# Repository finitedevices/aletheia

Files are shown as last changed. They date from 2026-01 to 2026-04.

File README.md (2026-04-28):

# Aletheia
Designs and resources for the Finite Aletheia: a versatile, 8-bit hand-bootstrapped computer.

## Building and running the simulator
Before building the simulator for the first time, ensure that development dependencies are installed by running:

```bash
cd simulator
./build.sh --install-dev
```

Once the dependencies are installed, the Aletheia simulator can be built and run by running the following in the `simulator` directory:

```bash
./build.sh && python3 -m http.server
```

The simulator will then be available at [localhost:8000](http://localhost:8000).

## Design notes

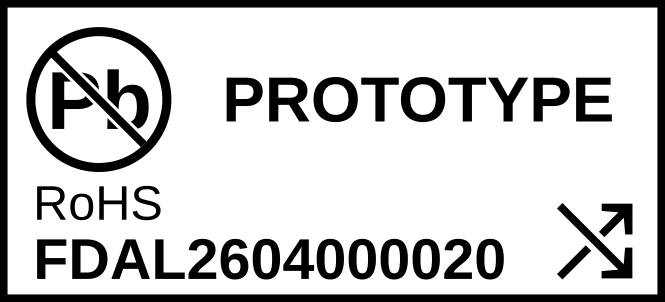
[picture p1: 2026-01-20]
hardware/Back-Cutout.png

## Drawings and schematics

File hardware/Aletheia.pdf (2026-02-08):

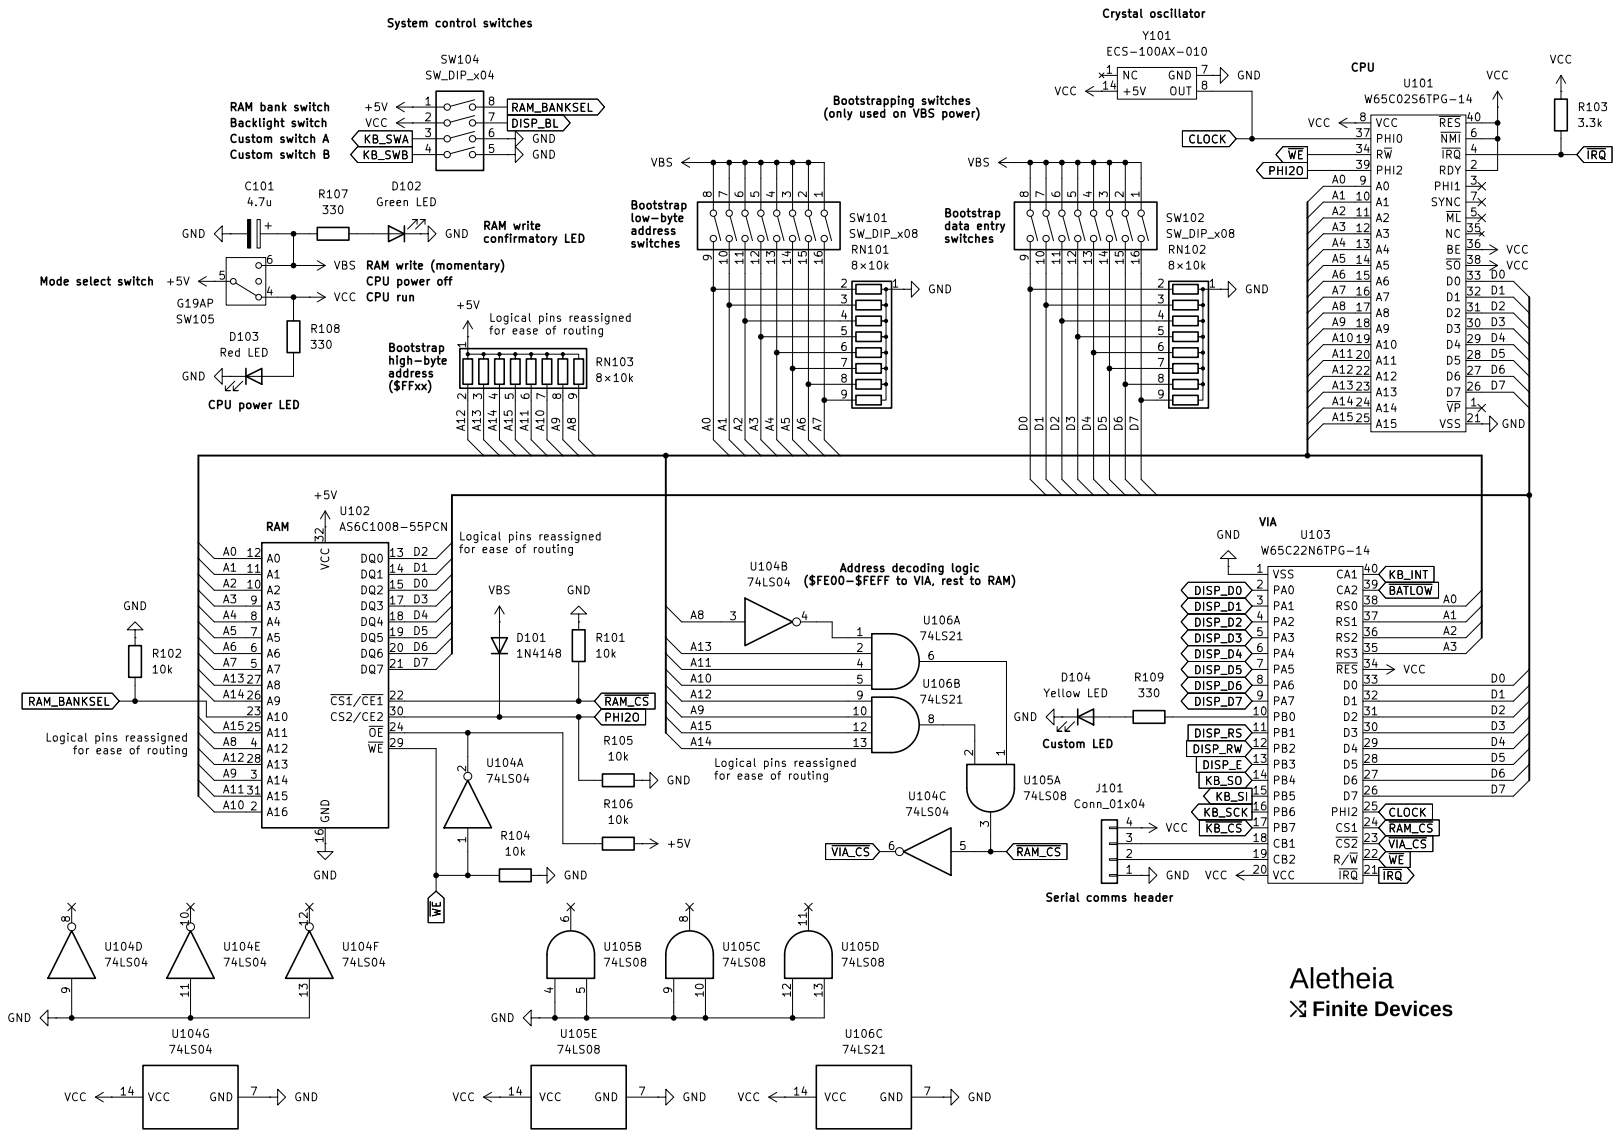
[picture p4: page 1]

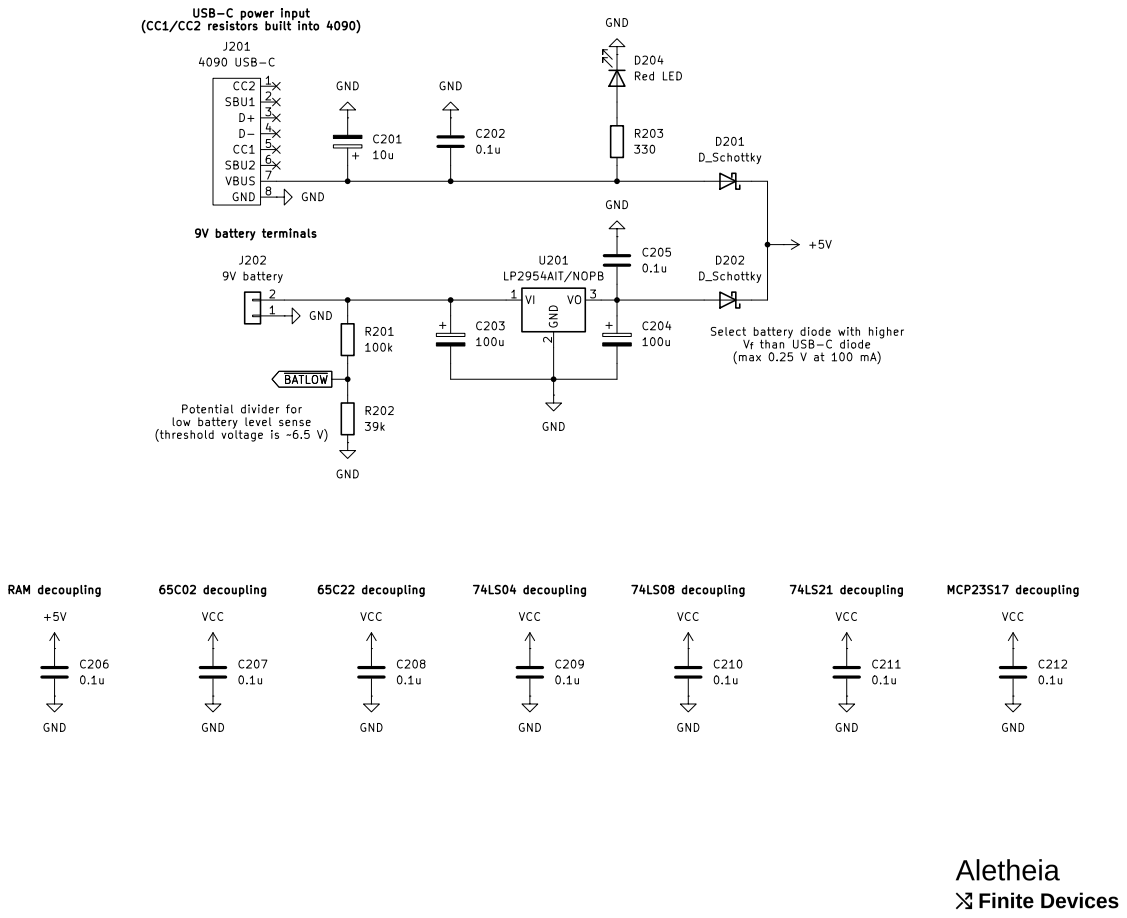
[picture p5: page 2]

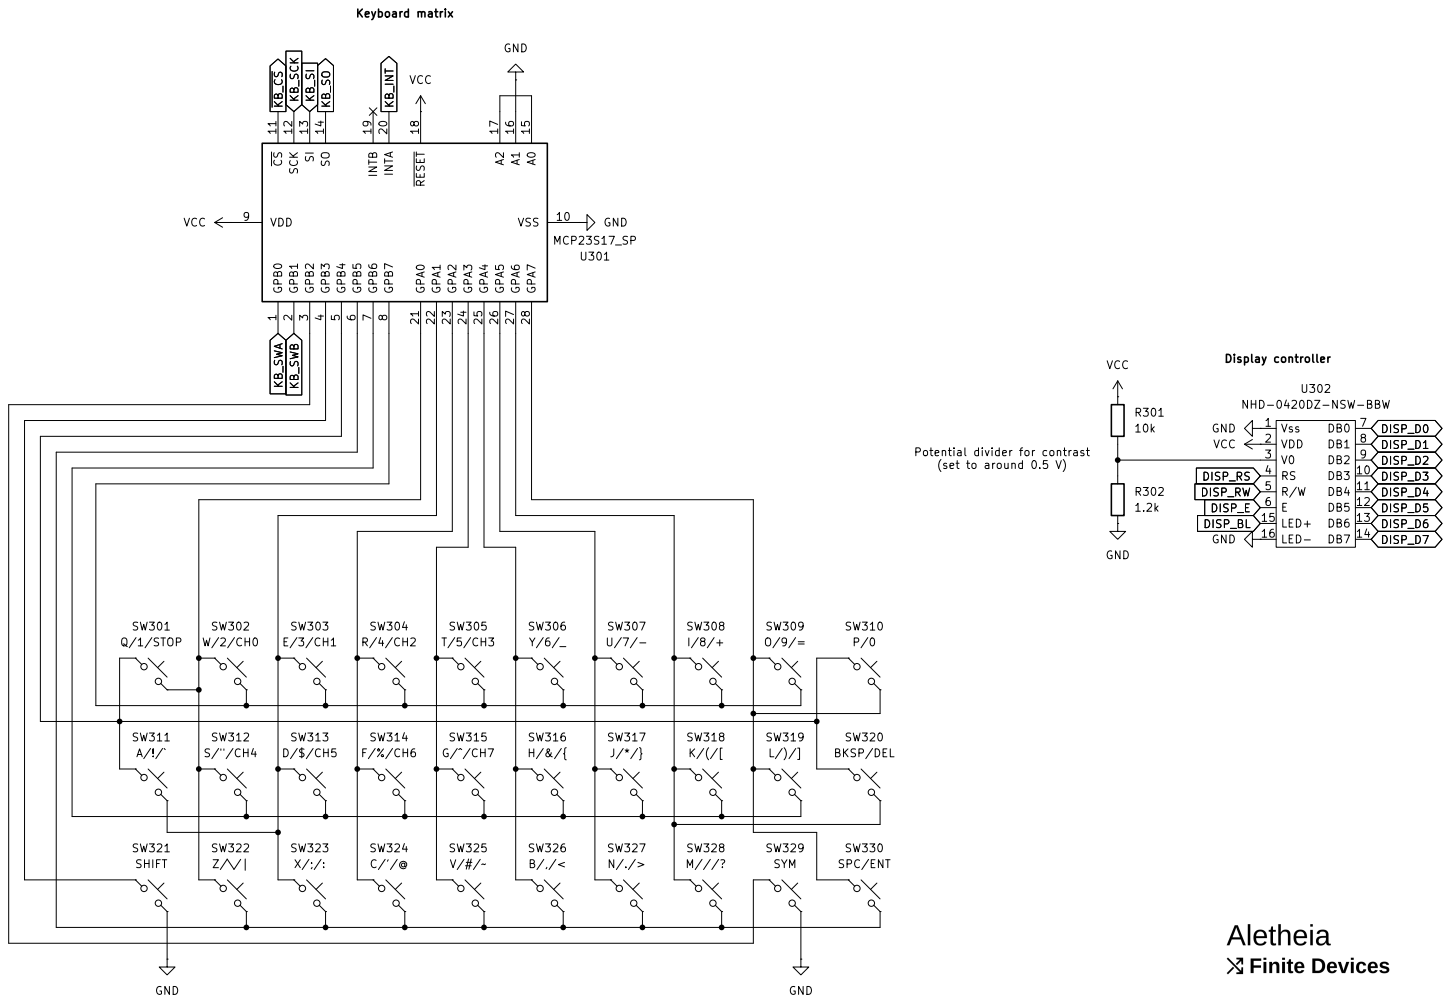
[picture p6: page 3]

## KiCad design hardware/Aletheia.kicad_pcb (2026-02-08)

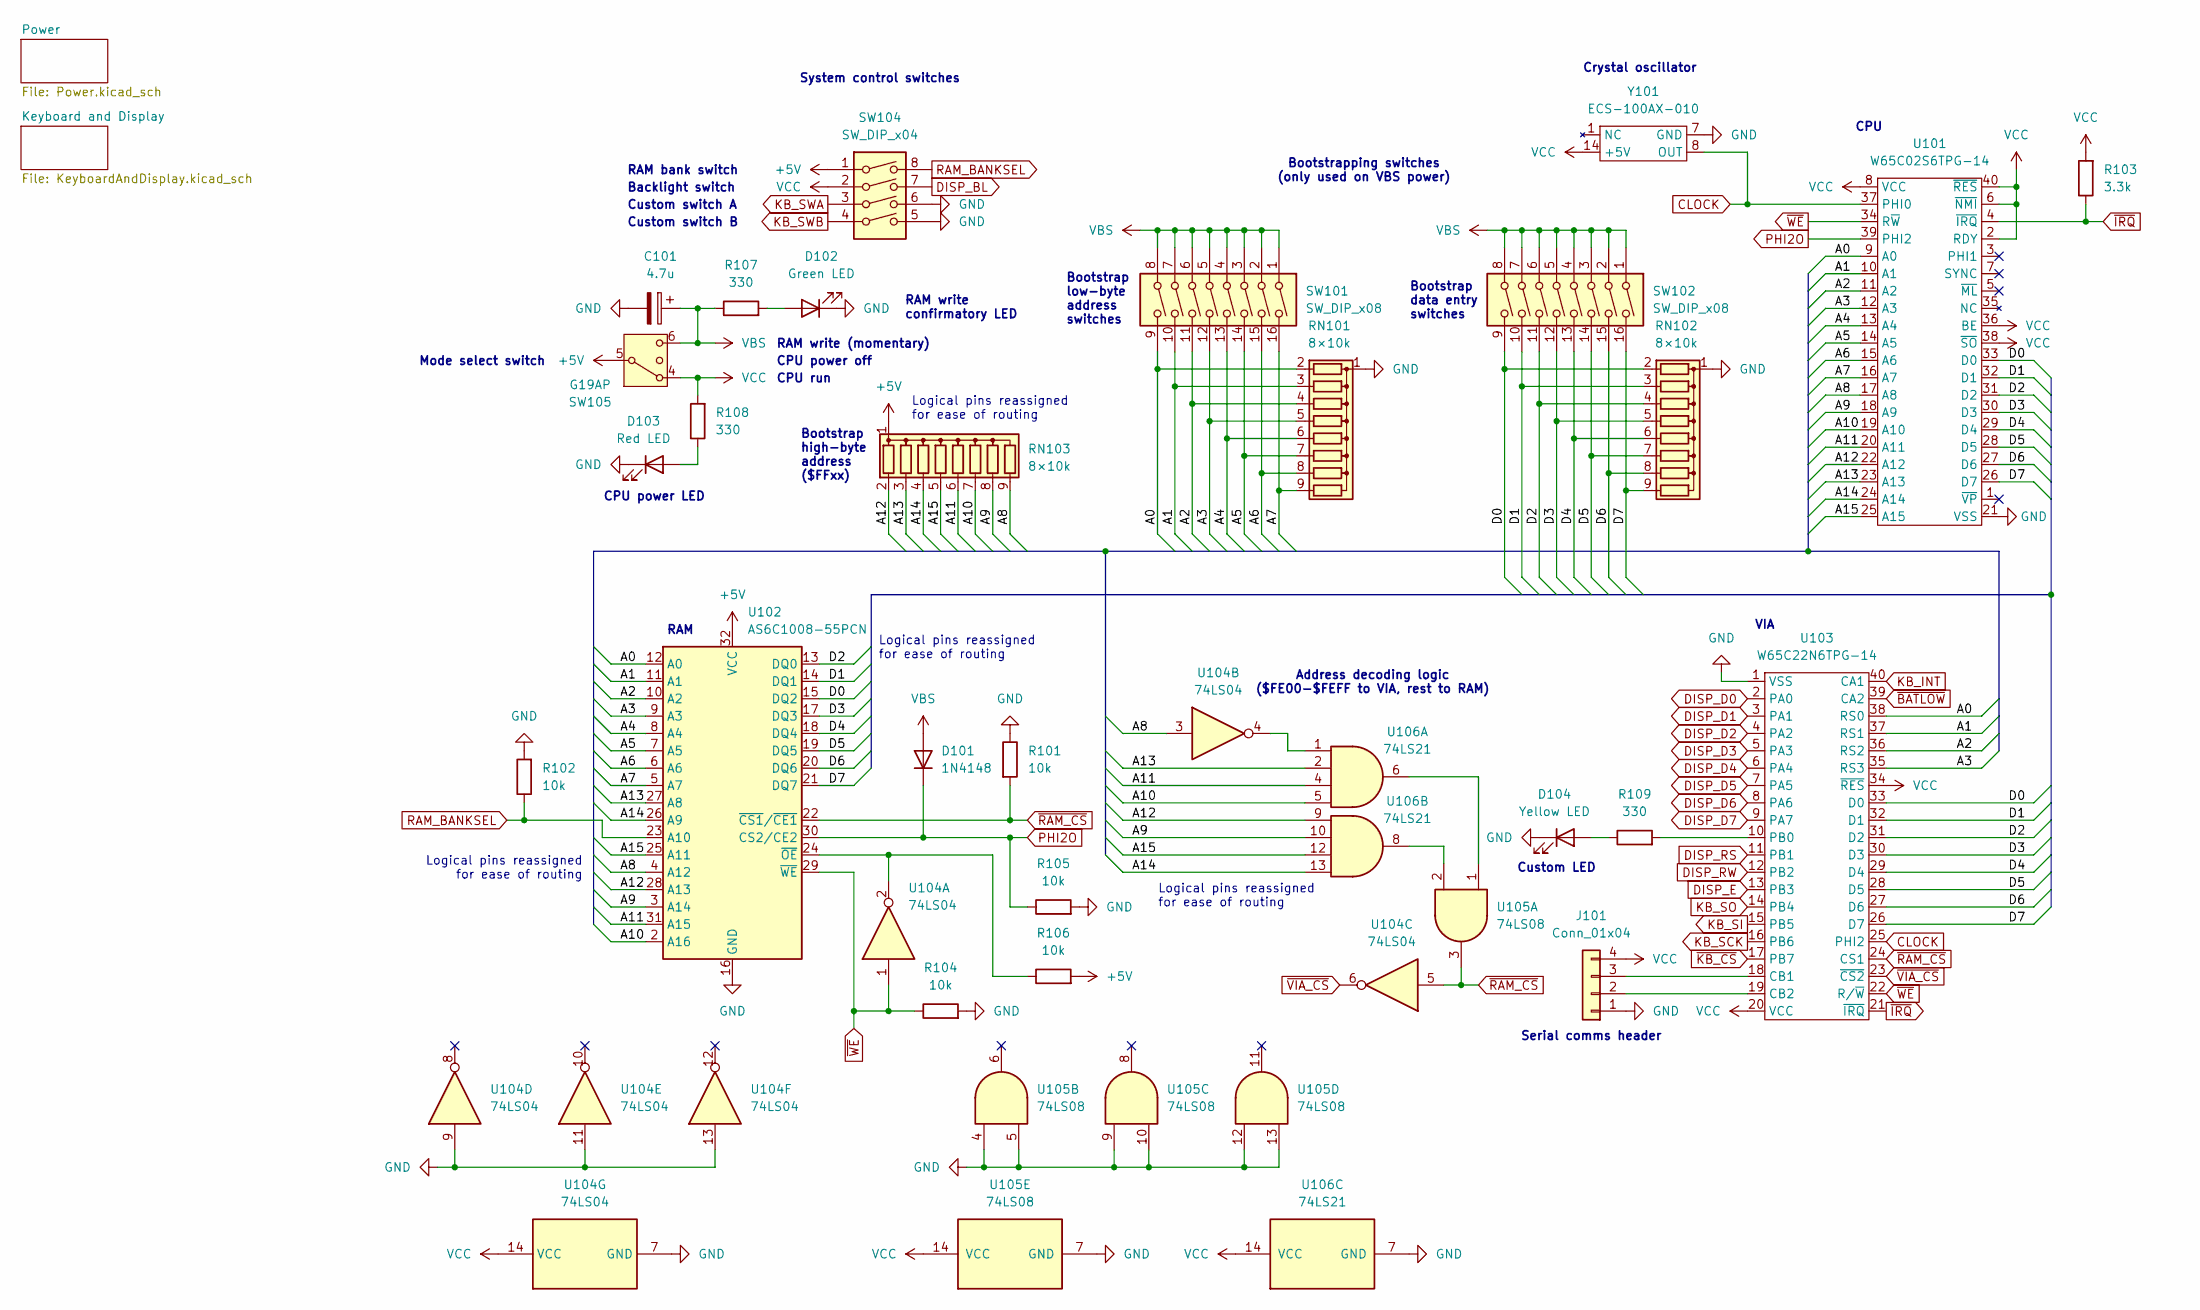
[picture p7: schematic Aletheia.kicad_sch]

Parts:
C101: 4.7u; CP_Radial_D5.0mm_P2.00mm
D101: 1N4148; D_DO-35_SOD27_P7.62mm_Horizontal
D102: Green LED; LED_D5.0mm
D103: Red LED; LED_D5.0mm
D104: Yellow LED; LED_D5.0mm
J101: Conn_01x04; PinHeader_1x04_P2.54mm_Vertical
R101, R102, R104, R105, R106: 10k; R_Axial_DIN0207_L6.3mm_D2.5mm_P7.62mm_Horizontal
R103: 3.3k; R_Axial_DIN0207_L6.3mm_D2.5mm_P7.62mm_Horizontal
R107, R108, R109: 330; R_Axial_DIN0207_L6.3mm_D2.5mm_P7.62mm_Horizontal
RN101, RN102, RN103: 8×10k; R_Array_SIP9
SW101, SW102: SW_DIP_x08; SW_DIP_SPSTx08_Slide_9.78x22.5mm_W7.62mm_P2.54mm
SW104: SW_DIP_x04; SW_DIP_SPSTx04_Slide_9.78x12.34mm_W7.62mm_P2.54mm
SW105: G19AP
U101: W65C02S6TPG-14; DIP-40_W15.24mm_LongPads
U102: AS6C1008-55PCN; DIP-32_W15.24mm
U103: W65C22N6TPG-14; DIP-40_W15.24mm
U104: 74LS04; DIP-14_W7.62mm
U105: 74LS08; DIP-14_W7.62mm
U106: 74LS21; DIP-14_W7.62mm
Y101: ECS-100AX-010

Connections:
+5V: R106.2, RN103.1 (common), SW104.1, SW105.5, U102.32 (VCC); also elsewhere on the board
/A0: RN101.2 (R1), SW101.9, U101.9 (A0), U102.12 (A0), U103.38 (RS0)
/A1: RN101.3 (R2), SW101.10, U101.10 (A1), U102.11 (A1), U103.37 (RS1)
/A2: RN101.4 (R3), SW101.11, U101.11 (A2), U102.10 (A2), U103.36 (RS2)
/A3: RN101.5 (R4), SW101.12, U101.12 (A3), U102.9 (A3), U103.35 (RS3)
/A4: RN101.6 (R5), SW101.13, U101.13 (A4), U102.8 (A4)
/A5: RN101.7 (R6), SW101.14, U101.14 (A5), U102.7 (A5)
/A6: RN101.8 (R7), SW101.15, U101.15 (A6), U102.6 (A6)
/A7: RN101.9 (R8), SW101.16, U101.16 (A7), U102.5 (A7)
/A8: RN103.9 (R8), U101.17 (A8), U102.4 (A12), U104.3
/A9: RN103.8 (R7), U101.18 (A9), U102.3 (A14), U106.10
/A10: RN103.7 (R6), U101.19 (A10), U102.2 (A16), U106.5
/A11: RN103.6 (R5), U101.20 (A11), U102.31 (A15), U106.4
/A12: RN103.2 (R1), U101.22 (A12), U102.28 (A13), U106.9
/A13: RN103.3 (R2), U101.23 (A13), U102.27 (A8), U106.2
/A14: RN103.4 (R3), U101.24 (A14), U102.26 (A9), U106.13
/A15: RN103.5 (R4), U101.25 (A15), U102.25 (A11), U106.12
/D0: RN102.2 (R1), SW102.9, U101.33 (D0), U102.15 (DQ2), U103.33 (D0)
/D1: RN102.3 (R2), SW102.10, U101.32 (D1), U102.14 (DQ1), U103.32 (D1)
/D2: RN102.4 (R3), SW102.11, U101.31 (D2), U102.13 (DQ0), U103.31 (D2)
/D3: RN102.5 (R4), SW102.12, U101.30 (D3), U102.17 (DQ3), U103.30 (D3)
/D4: RN102.6 (R5), SW102.13, U101.29 (D4), U102.18 (DQ4), U103.29 (D4)
/D5: RN102.7 (R6), SW102.14, U101.28 (D5), U102.19 (DQ5), U103.28 (D5)
/D6: RN102.8 (R7), SW102.15, U101.27 (D6), U102.20 (DQ6), U103.27 (D6)
/D7: RN102.9 (R8), SW102.16, U101.26 (D7), U102.21 (DQ7), U103.26 (D7)
CLOCK: U101.37 (PHI0), U103.25 (PHI2), Y101.8 (OUT)
DISP_BL: SW104.7; also elsewhere on the board
DISP_D0: U103.2 (PA0); also elsewhere on the board
DISP_D1: U103.3 (PA1); also elsewhere on the board
DISP_D2: U103.4 (PA2); also elsewhere on the board
DISP_D3: U103.5 (PA3); also elsewhere on the board
DISP_D4: U103.6 (PA4); also elsewhere on the board
DISP_D5: U103.7 (PA5); also elsewhere on the board
DISP_D6: U103.8 (PA6); also elsewhere on the board
DISP_D7: U103.9 (PA7); also elsewhere on the board
DISP_E: U103.13 (PB3); also elsewhere on the board
DISP_RS: U103.11 (PB1); also elsewhere on the board
DISP_RW: U103.12 (PB2); also elsewhere on the board
GND: C101.2, D102.1 (K), D103.1 (K), D104.1 (K), J101.1, R101.1, R102.2, R104.2, R105.2, RN101.1 (common), RN102.1 (common), SW104.5, SW104.6, U101.21 (VSS), U102.16 (GND), U103.1 (VSS), U104.7 (GND), U104.9, U104.11, U104.13, U105.4, U105.5, U105.7 (GND), U105.9, U105.10, U105.12, U105.13, U106.7 (GND), Y101.7 (GND); also elsewhere on the board
KB_INT: U103.40 (CA1); also elsewhere on the board
KB_SCK: U103.16 (PB6); also elsewhere on the board
KB_SI: U103.15 (PB5); also elsewhere on the board
KB_SO: U103.14 (PB4); also elsewhere on the board
KB_SWA: SW104.3; also elsewhere on the board
KB_SWB: SW104.4; also elsewhere on the board
unnamed: D102.2 (A), R107.2
unnamed: D103.2 (A), R108.1
unnamed: D104.2 (A), R109.1
unnamed: J101.2, U103.19 (CB2)
unnamed: J101.3, U103.18 (CB1)
unnamed: R106.1, U102.24 (~OE), U104.2
unnamed: R109.2, U103.10 (PB0)
unnamed: U104.4, U106.1
unnamed: U105.1, U106.6
unnamed: U105.2, U106.8
PHI2O: D101.1 (K), R105.1, U101.39 (PHI2), U102.30 (CS2/CE2)
RAM_BANKSEL: R102.1, SW104.8, U102.23 (A10)
VBS: C101.1, D101.2 (A), R107.1, SW101.1, SW101.2, SW101.3, SW101.4, SW101.5, SW101.6, SW101.7, SW101.8, SW102.1, SW102.2, SW102.3, SW102.4, SW102.5, SW102.6, SW102.7, SW102.8, SW105.6
VCC: J101.4, R103.2, R108.2, SW104.2, SW105.4, U101.2 (RDY), U101.6 (~NMI), U101.8 (VCC), U101.36 (BE), U101.38 (~SO), U101.40 (~RES), U103.20 (VCC), U103.34 (~RES), U104.14 (VCC), U105.14 (VCC), U106.14 (VCC), Y101.14 (+5V); also elsewhere on the board
~BATLOW: U103.39 (CA2); also elsewhere on the board
~IRQ: R103.1, U101.4 (~IRQ), U103.21 (~IRQ)
~KB_CS: U103.17 (PB7); also elsewhere on the board
~RAM_CS: R101.2, U102.22 (~CS1/~CE1), U103.24 (CS1), U104.5, U105.3
~VIA_CS: U103.23 (~CS2), U104.6
~WE: R104.1, U101.34 (R~W), U102.29 (~WE), U103.22 (R/~W), U104.1

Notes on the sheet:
Custom switch A
RAM
CPU
CPU run
Crystal oscillator
RAM write (momentary)
Bootstrap low-byte address switches
CPU power off
Bootstrap high-byte address ($FFxx)
Bootstrap data entry switches
Serial comms header
CPU power LED
Address decoding logic ($FE00-$FEFF to VIA, rest to RAM)
RAM write confirmatory LED
Bootstrapping switches (only used on VBS power)
Logical pins reassigned for ease of routing
VIA
Mode select switch
Backlight switch
RAM bank switch
Custom LED
System control switches
Custom switch B

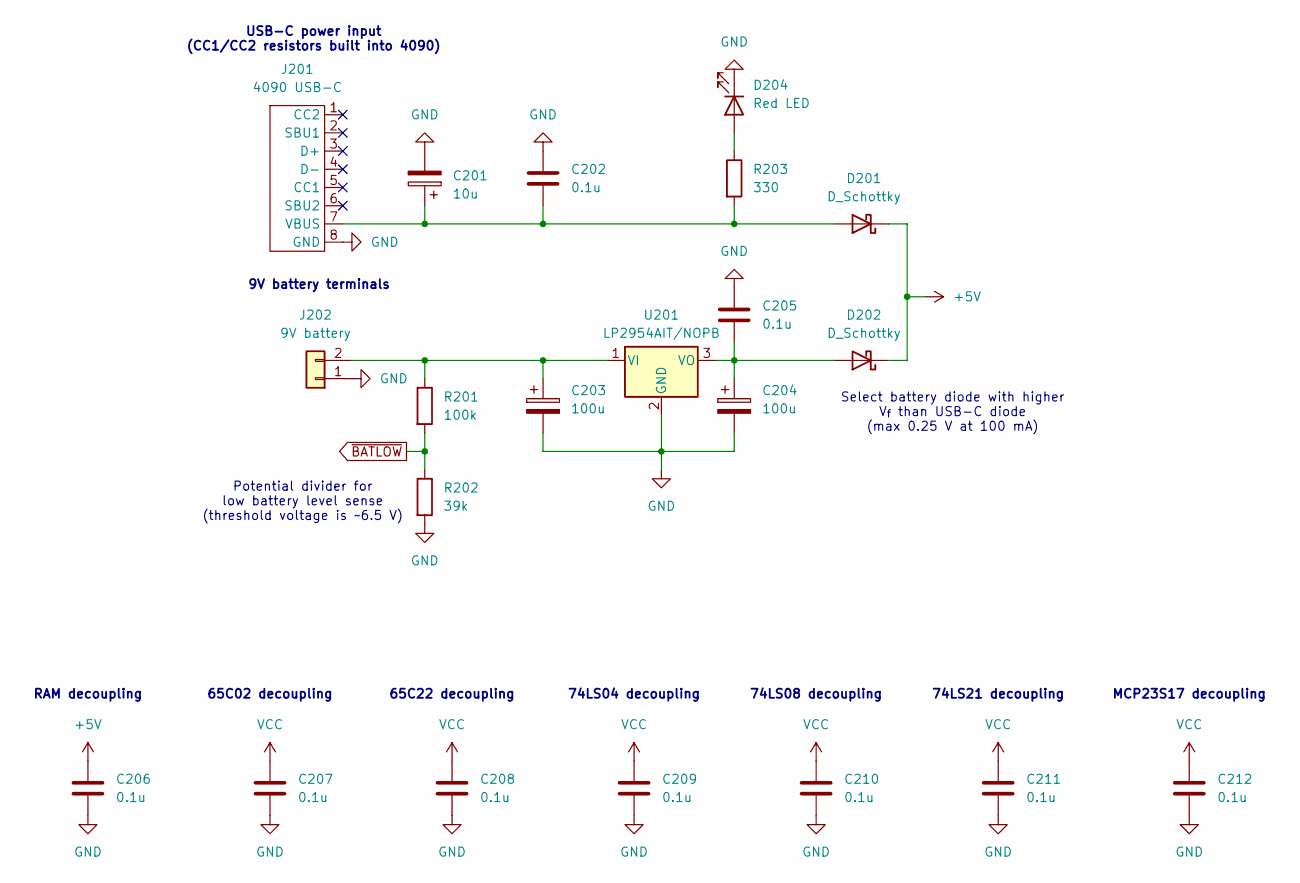
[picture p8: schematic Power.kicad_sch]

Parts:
C201: 10u; CP_Radial_D5.0mm_P2.00mm
C202: 0.1u; CP_Radial_D4.0mm_P1.50mm
C203, C204: 100u; CP_Radial_D6.3mm_P2.50mm
C205, C206, C207, C208, C209, C210, C211, C212: 0.1u; C_Radial_D4.0mm_H5.0mm_P1.50mm
D201, D202: D_Schottky; D_DO-41_SOD81_P7.62mm_Horizontal
D204: Red LED; LED_D5.0mm
J201: 4090 USB-C; PinHeader_1x08_P2.54mm_Vertical
J202: 9V battery; PinHeader_2x01_P2.54mm_Vertical
R201: 100k; R_Axial_DIN0207_L6.3mm_D2.5mm_P7.62mm_Horizontal
R202: 39k; R_Axial_DIN0207_L6.3mm_D2.5mm_P7.62mm_Horizontal
R203: 330; R_Axial_DIN0207_L6.3mm_D2.5mm_P7.62mm_Horizontal
U201: LP2954AIT/NOPB; TO-220-3_Vertical

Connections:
+5V: C206.1, D201.1 (K), D202.1 (K); also elsewhere on the board
GND: C201.2, C202.1, C203.2, C204.2, C205.1, C206.2, C207.2, C208.2, C209.2, C210.2, C211.2, C212.2, D204.1 (K), J201.8 (GND), J202.1, R202.2, U201.2 (GND); also elsewhere on the board
unnamed: C201.1, C202.2, D201.2 (A), J201.7 (VBUS), R203.2
unnamed: C204.1, C205.2, D202.2 (A), U201.3 (VO)
unnamed: D204.2 (A), R203.1
unnamed: C203.1, J202.2, R201.1, U201.1 (VI)
VCC: C207.1, C208.1, C209.1, C210.1, C211.1, C212.1; also elsewhere on the board
~BATLOW: R201.2, R202.1; also elsewhere on the board

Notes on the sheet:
RAM decoupling
74LS08 decoupling
MCP23S17 decoupling
Select battery diode with higher V_{f} than USB-C diode (max 0.25 V at 100 mA)
9V battery terminals
74LS04 decoupling
74LS21 decoupling
USB-C power input (CC1/CC2 resistors built into 4090)
65C02 decoupling
65C22 decoupling
Potential divider for low battery level sense (threshold voltage is ~6.5 V)

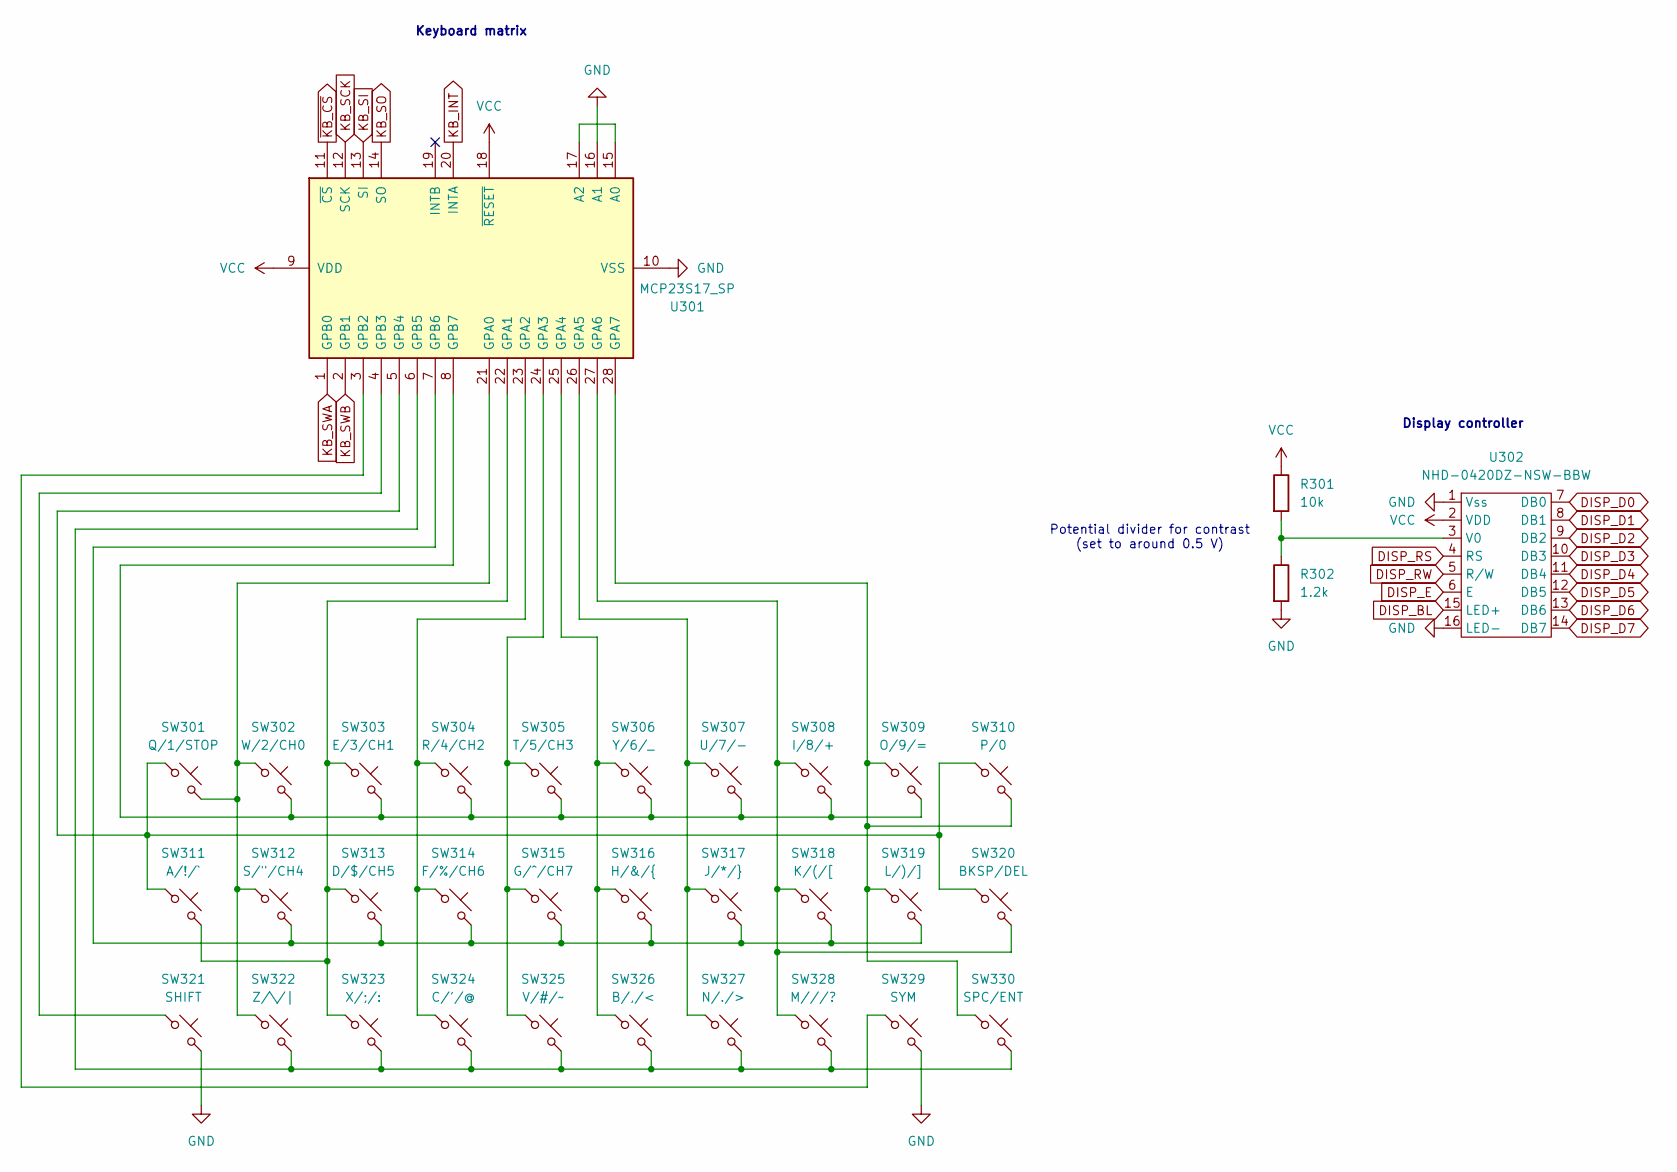
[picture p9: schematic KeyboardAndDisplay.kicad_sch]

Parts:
R301: 10k; R_Axial_DIN0207_L6.3mm_D2.5mm_P7.62mm_Horizontal
R302: 1.2k; R_Axial_DIN0207_L6.3mm_D2.5mm_P7.62mm_Horizontal
SW301: Q/1/STOP; SW_PUSH_6mm
SW302: W/2/CH0; SW_PUSH_6mm
SW303: E/3/CH1; SW_PUSH_6mm
SW304: R/4/CH2; SW_PUSH_6mm
SW305: T/5/CH3; SW_PUSH_6mm
SW306: Y/6/_; SW_PUSH_6mm
SW307: U/7/-; SW_PUSH_6mm
SW308: I/8/+; SW_PUSH_6mm
SW309: O/9/=; SW_PUSH_6mm
SW310: P/0; SW_PUSH_6mm
SW311: A/!/`; SW_PUSH_6mm
SW312: S/"/CH4; SW_PUSH_6mm
SW313: D/$/CH5; SW_PUSH_6mm
SW314: F/%/CH6; SW_PUSH_6mm
SW315: G/^/CH7; SW_PUSH_6mm
SW316: H/&/{; SW_PUSH_6mm
SW317: J/*/}; SW_PUSH_6mm
SW318: K/(/[; SW_PUSH_6mm
SW319: L/)/]; SW_PUSH_6mm
SW320: BKSP/DEL; SW_PUSH_6mm
SW321: SHIFT; SW_PUSH_6mm
SW322: Z/\/|; SW_PUSH_6mm
SW323: X/;/:; SW_PUSH_6mm
SW324: C/'/@; SW_PUSH_6mm
SW325: V/#/~; SW_PUSH_6mm
SW326: B/,/<; SW_PUSH_6mm
SW327: N/./>; SW_PUSH_6mm
SW328: M///?; SW_PUSH_6mm
SW329: SYM; SW_PUSH_6mm
SW330: SPC/ENT; SW_PUSH_6mm
U301: MCP23S17_SP; DIP-28_W7.62mm
U302: NHD-0420DZ-NSW-BBW; NHD-0420DZ-FL-YBW

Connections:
DISP_BL: U302.15 (LED+); also elsewhere on the board
DISP_D0: U302.7 (DB0); also elsewhere on the board
DISP_D1: U302.8 (DB1); also elsewhere on the board
DISP_D2: U302.9 (DB2); also elsewhere on the board
DISP_D3: U302.10 (DB3); also elsewhere on the board
DISP_D4: U302.11 (DB4); also elsewhere on the board
DISP_D5: U302.12 (DB5); also elsewhere on the board
DISP_D6: U302.13 (DB6); also elsewhere on the board
DISP_D7: U302.14 (DB7); also elsewhere on the board
DISP_E: U302.6 (E); also elsewhere on the board
DISP_RS: U302.4 (RS); also elsewhere on the board
DISP_RW: U302.5 (R/W); also elsewhere on the board
GND: R302.2, SW321.2, SW329.2, U301.10 (VSS), U301.16 (A1), U302.1 (Vss), U302.16 (LED-); also elsewhere on the board
KB_INT: U301.20 (INTA); also elsewhere on the board
KB_SCK: U301.12 (SCK); also elsewhere on the board
KB_SI: U301.13 (SI); also elsewhere on the board
KB_SO: U301.14 (SO); also elsewhere on the board
KB_SWA: U301.1 (GPB0); also elsewhere on the board
KB_SWB: U301.2 (GPB1); also elsewhere on the board
unnamed: U301.15 (A0), U301.17 (A2)
unnamed: SW301.2, SW302.1, SW312.1, SW322.1, U301.21 (GPA0)
unnamed: SW303.1, SW311.2, SW313.1, SW323.1, U301.22 (GPA1)
unnamed: SW304.1, SW314.1, SW324.1, U301.23 (GPA2)
unnamed: SW305.1, SW315.1, SW325.1, U301.24 (GPA3)
unnamed: SW306.1, SW316.1, SW326.1, U301.25 (GPA4)
unnamed: SW307.1, SW317.1, SW327.1, U301.26 (GPA5)
unnamed: SW308.1, SW318.1, SW320.2, SW328.1, U301.27 (GPA6)
unnamed: SW309.1, SW310.2, SW319.1, SW330.1, U301.28 (GPA7)
unnamed: SW329.1, U301.3 (GPB2)
unnamed: SW321.1, U301.4 (GPB3)
unnamed: SW301.1, SW310.1, SW311.1, SW320.1, U301.5 (GPB4)
unnamed: SW322.2, SW323.2, SW324.2, SW325.2, SW326.2, SW327.2, SW328.2, SW330.2, U301.6 (GPB5)
unnamed: SW312.2, SW313.2, SW314.2, SW315.2, SW316.2, SW317.2, SW318.2, SW319.2, U301.7 (GPB6)
unnamed: SW302.2, SW303.2, SW304.2, SW305.2, SW306.2, SW307.2, SW308.2, SW309.2, U301.8 (GPB7)
unnamed: R301.2, R302.1, U302.3 (V0)
VCC: R301.1, U301.9 (VDD), U301.18 (~RESET), U302.2 (VDD); also elsewhere on the board
~KB_CS: U301.11 (~CS); also elsewhere on the board

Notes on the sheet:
Display controller
Keyboard matrix
Potential divider for contrast (set to around 0.5 V)

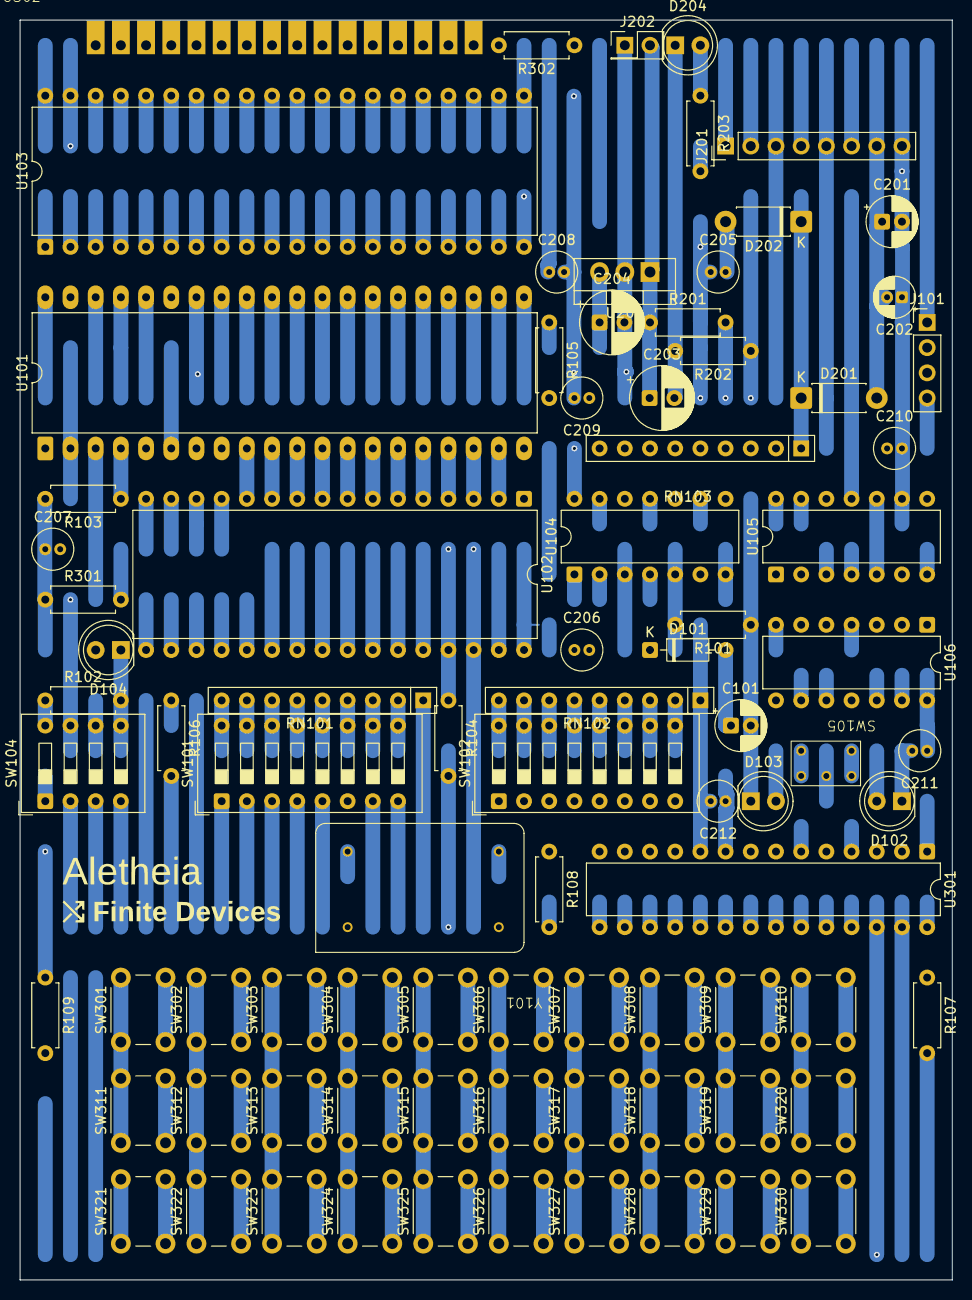
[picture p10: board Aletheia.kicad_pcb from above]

Board: 12 copper layers, 94.0 x 127.0 mm, 84 parts (0 on the bottom side), 85 nets.

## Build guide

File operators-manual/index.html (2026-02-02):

# Aletheia Operator's Manual

# Table of contents

- General safety notices
- Safe battery replacement process
- Getting started
- Compliance information

# General safety notices

## Warning! Risk of fire or serious personal injury!

- Do not place the Aletheia on any any conductive surface or let any conductive materials or liquids come into contact with the Aletheia.
- Immediately remove both the battery and any connected USB-C cable if the Aletheia is hot to the touch, but only if it is safe to do so.
- Handle the Aletheia with care as the corners of its circuit board and any protruding legs of mounted components may be sharp.
- Ensure that any connected batteries or power adapters meet local regulations on electrical safety; and that connected batteries are rated for 9 V output, and power adapters are rated for 5 V output. USB-C Power Delivery capable power adapters may be used, but must be fully compliant with the USB-C Power Delivery specifications to prevent overvoltage.
- Children should be supervised by a responsible adult when using the Aletheia.
- The Aletheia contains small parts which could present a choking hazard to children 0–3 years of age.

## Caution! Risk of causing permanent damage to the Aletheia

- The Aletheia contains precision components which are sensitive to electrostatic discharge. Ensure that electrostatic discharge protection is used when handling the Aletheia.
- Do not drop the Aletheia as this could cause significant damage to its circuit board or exposed components.
- Do not place heavy items on top of the Aletheia as those items could scratch or damage its components.
- Ensure that the Aletheia is sufficiently protected when storing it in bags or containers. Wrapping the Aletheia in non-conductive protective materials (such as bubble wrap) can help to avoid damage during transport.
- Do not use the Aletheia in temperatures above 70 °C (158 °F) or below 0 °C (32 °F).
- While the Aletheia has protections against connecting the battery terminals in the reverse polarity, ensure that terminals are connected in the correct polarity to minimise the risk of component damage.
- If storing the Aletheia for extended periods, back up stored data and remove the battery.

## Caution! Risk of losing data stored in the Aletheia's memory

- To prevent data loss, ensure that any data stored on the Aletheia is backed up.
- Do not remove the battery unless absolutely necessary or as part of performing the safe battery replacement process.
- When the connected battery is low on charge, ensure that it is replaced at the earliest convenience using the safe battery replacement process.
- Do not flip the RAM bank switch while the mode select switch is in the CPU RUN mode.

# Safe battery replacement process

All data is stored on the Aletheia's random access memory (RAM). This memory is volatile, which means that all data stored on it is cleared when the Aletheia is completely depowered. When replacing the Aletheia's battery, care must be taken to ensure that the Aletheia still receives a stable source of power to prevent the contents of RAM from being cleared.

The following battery replacement process significantly reduces the risk of data loss from occuring when performing a battery replacement. Finite Devices advises those replacing the Aletheia's battery to make a backup of the data stored on the Aletheia prior to battery replacement, if possible.

1. Ensure that the mode select switch is in the CPU OFF mode.
2. Connect a 5 V power source to the Aletheia via the USB-C socket using a USB-C cable. Typical phone charger power adapters are usually acceptable to ensure a stable power source.
3. Before proceeding, ensure that the red external power supply LED lamp next to the Aletheia's USB-C socket is illuminated and steady.
4. Disconnect the 9 V battery from the Aletheia's battery connector. Do this with care to ensure that the USB-C cable is not accidentally disconnected.
5. Connect a new, unused 9 V battery to the Aletheia's battery connector.
6. Disconnect the 5 V power source and USB-C cable. Ensure that the new battery remains connected.
7. Verify that the Aletheia continues to work as intended by putting the mode select switch into the CPU run mode.

# Getting started

Congratulations on becoming the owner of an Aletheia. You now own a versatile computer that is principally designed to give you full control over the software you wish to use on it. This guide helps you to become acquainted with the Aletheia — and, over time — takes you through a guided process that intends to teach you about the Aletheia's internal features, with the end goal of setting it up to become a powerful computing environment.

The Aletheia does not come with any built-in software — you, as the operator, are responsible for loading in all software for it, by hand; the only means of initially loading software onto it is through the miniature array of switches situated above the keyboard. While this may make the Aletheia appear to be critically limited from a modern computing perspective, this limitation is intentional — it ensures that the operator gains full knowledge over the Aletheia's internals; it eliminates entire classes of problems experienced with modern technology (including network security threats, and planned obselescence through software design); and it encourages operators to write their own software or build their own derivatives of the Aletheia hardware to solve their own problems.

The Aletheia's name is a romanised form of the Ancient Greek word ἀλήθεια, which is commonly interpreted as meaning the process of disclosing information. This is fitting for the Aletheia, as it is the operator's responsibility to gradually introduce new software components to the system and get it into a usable, desired state over time.

# Compliance information

Lead free WEEE compliant

## United Kingdom; European Union

In line with all electronics subject to WEEE regulations, the Aletheia should not be disposed of in household waste within the United Kingdom or European Union.

RoHS 2 (Directive 2011/65/EU) has restrictions on the use of the following hazardous substances in electronics products: lead, mercury, cadmium, hexavalent chromium, polybrominated biphenyls (PBB), and polybrominated diphenyl ethers (PBDE). RoHS 3 (Directive 2015/863/EU) includes additional hazardous substances: Bis(2-ethylhexyl) phthalate (DEHP), Dibutyl phthalate (DBP), Butyl benzyl phthalate (BBP), and Diisobutyl phthalate (DIBP). The maximum allowed concentration (by weight) for hazardous substances is 0.1%, save for cadmium, at 0.01%. Finite Devices hereby declares that the Aletheia does not utilise any of the listed hazardous substances during manufacturing.

## United States of America

### PROTOTYPE — NOT FOR SALE

This device has not been authorized as required by the rules of the Federal Communications Commission. This device is not, and may not be, offered for sale or lease, or sold or leased, until authorization is obtained.

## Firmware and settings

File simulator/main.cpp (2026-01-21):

#include <stdio.h>
#include <emscripten.h>
#include <emscripten/bind.h>

#include "vrEmu6502.h"
#include "vrEmu6522.h"
#include "vrEmuLcd.h"

#define INSTANCES 4
#define BANKED_ADDR(addr) (((active_instance->system_dips & 0x04) ? 0x10000 : 0) | addr)

enum {
    MODE_OFF = 0,
    MODE_RAM_WRITE = 1,
    MODE_CPU_RUN = 2
};

typedef uint8_t mode_t;
typedef size_t instanceid_t;

struct aletheia {
    uint8_t ram[0x20000]; // 128 KiB
    VrEmu6502* cpu;
    VrEmu6522* via;
    VrEmuLcd* lcd;
    mode_t mode = MODE_OFF;
    uint8_t system_dips = 0;
    uint8_t addr_dips = 0;
    uint8_t data_dips = 0;
};

struct aletheia instances[INSTANCES];
struct aletheia* active_instance = 0;
const unsigned int lcd_buffer_row_size = (20 * 6) / 8;
uint8_t current_lcd_buffer[lcd_buffer_row_size * (4 * 9)];

EM_JS(void, send_lcd_bitmap, (instanceid_t instance, uint8_t* data, uint32_t size), {
    renderLcdBitmap(instance, new Uint8ClampedArray(HEAPU8.buffer.slice(data), 0, size));
});

uint8_t ram_read(uint16_t addr, bool is_debug) {
    if ((addr & 0xFF00) == 0xFE00) {
        return vrEmu6522Read(active_instance->via, addr);
    }

    return active_instance->ram[BANKED_ADDR(addr)];
}

void ram_write(uint16_t addr, uint8_t data) {
    if ((addr & 0xFF00) == 0xFE00) {
        bool orig_lcd_enable = vrEmu6522ReadDbg(active_instance->via, 0) & 0x08;

        vrEmu6522Write(active_instance->via, addr, data);

        uint8_t paState = vrEmu6522ReadDbg(active_instance->via, 1);
        uint8_t pbState = vrEmu6522ReadDbg(active_instance->via, 0);

        if (!orig_lcd_enable && pbState & 0x08) {
            if (pbState & 0x04) { // If reading
                vrEmu6522Write(active_instance->via, 1, vrEmuLcdReadByteNoInc(active_instance->lcd));
            } else if (pbState & 0x02) { // If register selected
                vrEmuLcdSendCommand(active_instance->lcd, paState);
            } else {
                vrEmuLcdWriteByte(active_instance->lcd, paState);
            }
        }

        return;
    }

    active_instance->ram[BANKED_ADDR(addr)] = data;
}

void setup() {
    for (instanceid_t i = 0; i < INSTANCES; i++) {
        active_instance = &instances[i];
        active_instance->cpu = vrEmu6502New(CPU_W65C02, ram_read, ram_write);
        active_instance->via = vrEmu6522New(VIA_65C22);
        active_instance->lcd = vrEmuLcdNew(20, 4, EmuLcdRomA00);
    }
}

void loop() {
    for (instanceid_t i = 0; i < INSTANCES; i++) {
        active_instance = &instances[i];

        if (active_instance->mode == MODE_RAM_WRITE) {
            active_instance->ram[BANKED_ADDR(active_instance->addr_dips) | 0xFF00] = active_instance->data_dips;
        }

        if (active_instance->mode == MODE_CPU_RUN) {
            for (unsigned int j = 0; j < 256; j++) {
                vrEmu6502Tick(active_instance->cpu);
                vrEmu6522Tick(active_instance->via);

                *vrEmu6502Int(active_instance->cpu) = *vrEmu6522Int(active_instance->via);
            }
        }

        VrEmuLcd* lcd = active_instance->lcd;

        vrEmuLcdUpdatePixels(lcd);

        for (unsigned int y = 0; y < sizeof(current_lcd_buffer) / lcd_buffer_row_size; y++) {
            for (unsigned int xByte = 0; xByte < lcd_buffer_row_size; xByte++) {
                uint8_t byte = 0;

                for (unsigned int x = xByte * 8; x < (xByte + 1) * 8; x++) {
                    int8_t pixel = vrEmuLcdPixelState(lcd, x, y);

                    byte >>= 1;
                    byte |= pixel == 1 ? 0x80 : 0;
                }

                current_lcd_buffer[(y * lcd_buffer_row_size) + xByte] = byte;
            }
        }

        send_lcd_bitmap(i, current_lcd_buffer, sizeof(current_lcd_buffer));
    }
}

void set_mode(instanceid_t instance, mode_t new_mode) {
    if (instance >= INSTANCES) {
        return;
    }

    active_instance = &instances[instance];

    if (active_instance->mode != MODE_CPU_RUN && new_mode == MODE_CPU_RUN) {
        vrEmu6502Reset(active_instance->cpu);
        vrEmu6522Reset(active_instance->via);

        if (active_instance->lcd) {
            vrEmuLcdDestroy(active_instance->lcd);
        }

        active_instance->lcd = vrEmuLcdNew(20, 4, EmuLcdRomA00);
    }

    active_instance->mode = new_mode;
}

void set_dips(instanceid_t instance, uint8_t system, uint8_t addr, uint8_t data) {
    if (instance >= INSTANCES) {
        return;
    }

    active_instance = &instances[instance];

    active_instance->system_dips = system;
    active_instance->addr_dips = addr;
    active_instance->data_dips = data;
}

bool get_custom_led(instanceid_t instance) {
    if (instance >= INSTANCES) {
        return 0;
    }

    return vrEmu6522ReadDbg(instances[instance].via, 0) & 0x01;
}

extern "C" void load_code(instanceid_t instance, uint8_t* code, uint16_t offset, uint16_t length) {
    if (instance >= INSTANCES) {
        return;
    }

    active_instance = &instances[instance];

    for (uint16_t i = 0; i < length; i++) {
        ram_write(offset + i, code[i]);
    }
}

EMSCRIPTEN_BINDINGS(aletheia) {
    emscripten::function("setup", &setup);
    emscripten::function("loop", &loop);
    emscripten::function("setMode", &set_mode);
    emscripten::function("setDips", &set_dips);
    emscripten::function("getCustomLed", &get_custom_led);
}

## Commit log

2026-01-13 Add final planned components
    [FCom-8.kicad_pcb, FCom-8.kicad_sch, KeyboardAndDisplay.kicad_sch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]
2026-01-14 Finish rough component wiring layout
    [FCom-8.kicad_pcb, FCom-8.kicad_sch]
2026-01-15 Modify power circuitry to use better diode arrangement and more energy-efficient regulator
    [FCom-8.kicad_pcb, FCom-8.kicad_sch, KeyboardAndDisplay.kicad_sch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]
2026-01-17 Fix badge branding
    [Aletheia.kicad_pcb]
2026-01-21 Fix footprint for crystal
    [Aletheia.kicad_pcb]
2026-01-25 Fix wiring of crystal oscillator
    [Aletheia.kicad_pcb]
2026-02-06 Add DIP switches to 3D visualisation
2026-02-07 Fix missing trace wire in hardware
    [Aletheia.kicad_pcb]
2026-02-08 Fix orientation of pins for mode switch in hardware
    [Aletheia.kicad_pcb, Aletheia.kicad_sch]
